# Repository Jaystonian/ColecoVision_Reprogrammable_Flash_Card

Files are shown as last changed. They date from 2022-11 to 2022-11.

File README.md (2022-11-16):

# ColecoVision_Reprogrammable_Flash_Card
An opensource, reprogrammable cartridge for the ColecoVision

MODES OF USE:

A) Single flash chip
- select 32KB or 16KB rom type (J1/JP1)
- select 80-BF for typical 16KB roms, or 80-FF for 32KB roms.
- 2nd flash chip must be absent and its jumpers may be ignored.

B) Dual flash chips (32KB double memory)
- select 16KB rom type (J1/JP1)
- One chip must select 80-BF and contain an array of the lower 16KB of each 32KB rom, the other must select C0-FF and contain the upper 16KB. 
- Your roms will need to be split in half for two 16KB binary files (low and high). Then concatenated into a low file and a high file, for writing.

**NOTES**
All modes require 32KB mode for re-programming flash chips.
Re-programming also requires SW2 switches to all be OPEN and
J2/JP2 must be PROG. Revert jumper back to USE when finished.
The re-programming adapter must have the pullups for block select and a
jumper to select which flash chip to reprogram.

While in 16KB mode, single or dual chip, Address 14 (A14) in SW2 
Memory Select will be included in selecting memory. 32KB mode will
require A14 and this jumper switch will be ignored by J1/JP1 configuration,
allowing the installation of a smaller DIP switch. If you use a single, smaller
Flash chip such as the SST39SF010A (instead of the 'F04) then you do not
need switches for A18 or A17, reducing it to two toggle switches for
four 32KB roms on A15 and A16.

Dual-flash uses dual 16KB for 32KB roms, so the A14 switch is needed to address roms.

8-12KB ROMs must be right-padded to 16KB with 0's.
20-24KB ROMs must be right-padded to 32KB with 0's.

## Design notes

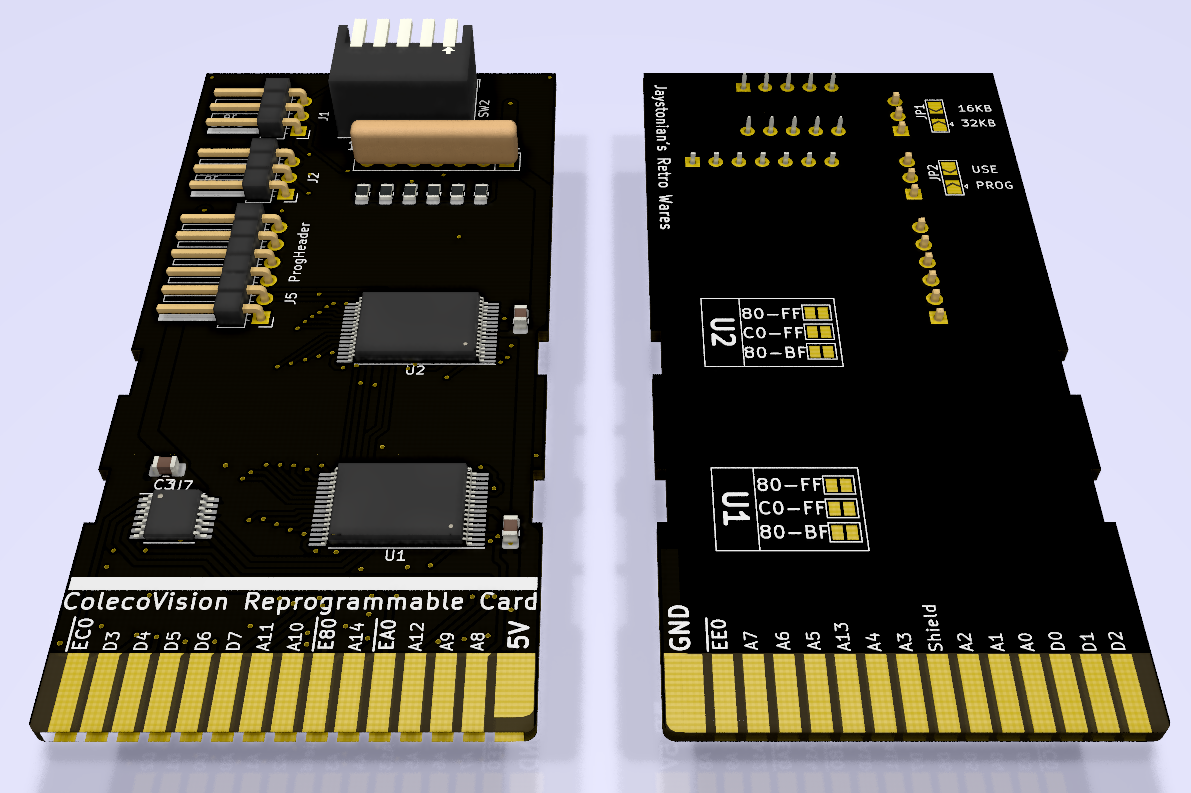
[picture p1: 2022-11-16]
img/Coleco-Card3.png

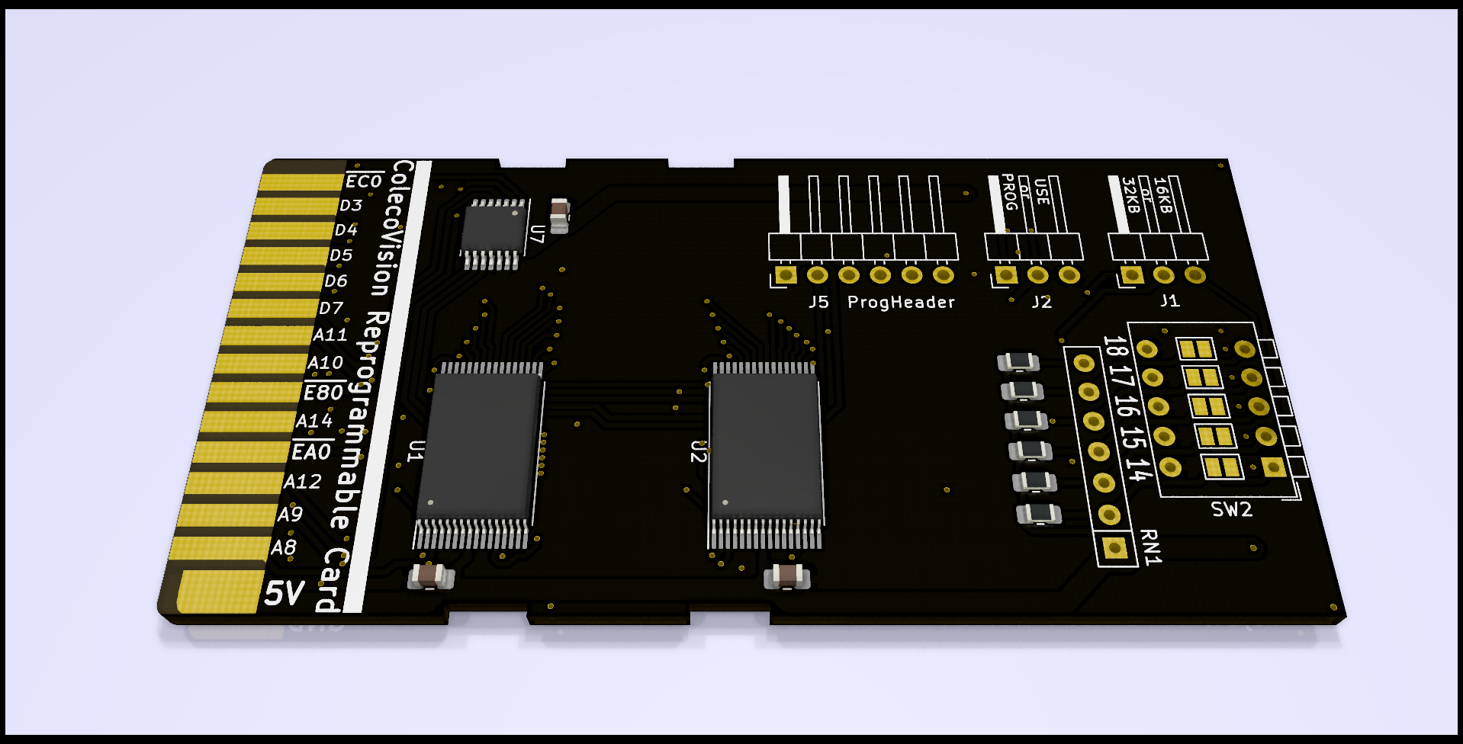
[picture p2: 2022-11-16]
img/Coleco-Card3s.png

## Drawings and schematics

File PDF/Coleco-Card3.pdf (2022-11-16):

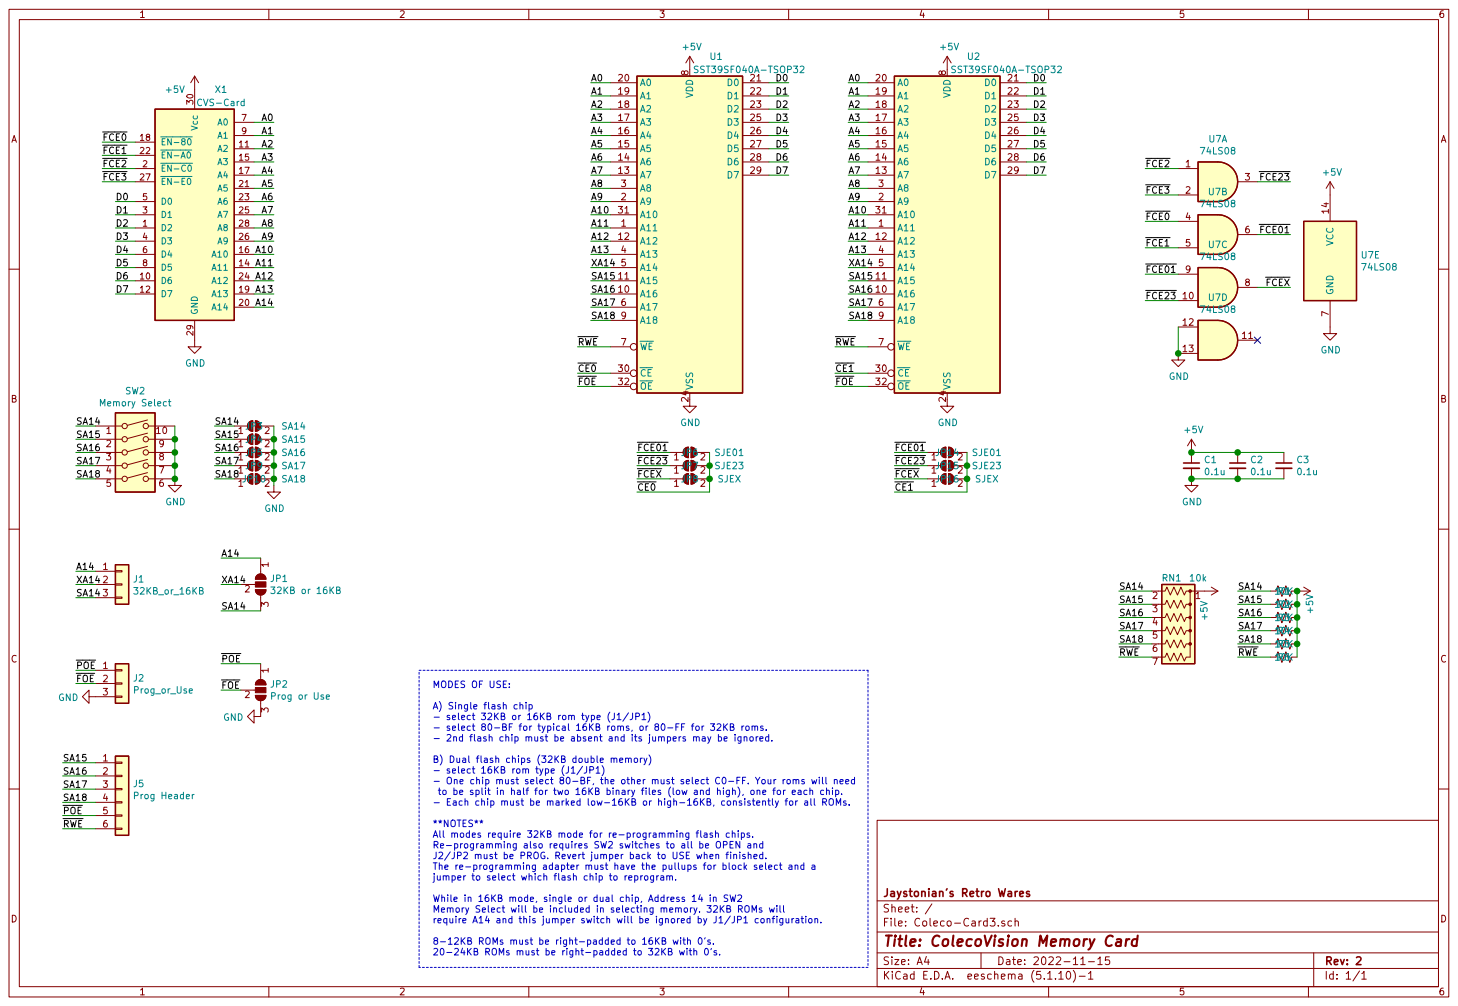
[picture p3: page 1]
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

B) Dual flash chips (32KB double memory)
- select 16KB rom type (J1/JP1)
- One chip must select 80-BF, the other must select C0-FF. Your roms will need
to be split in half for two 16KB binary files (low and high), one for each chip.
- Each chip must be marked low-16KB or high-16KB, consistently for all ROMs. **NOTES** All modes require 32KB mode for re-programming flash chips.

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

File: Coleco-Card3.sch Sheet: / Jaystonian's Retro Wares

While in 16KB mode, single or dual chip, Address 14 in SW2
Memory Select will be included in selecting memory. 32KB ROMs will
require A14 and this jumper switch will be ignored by J1/JP1 configuration.

Id: 1/1 Title: ColecoVision Memory Card

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

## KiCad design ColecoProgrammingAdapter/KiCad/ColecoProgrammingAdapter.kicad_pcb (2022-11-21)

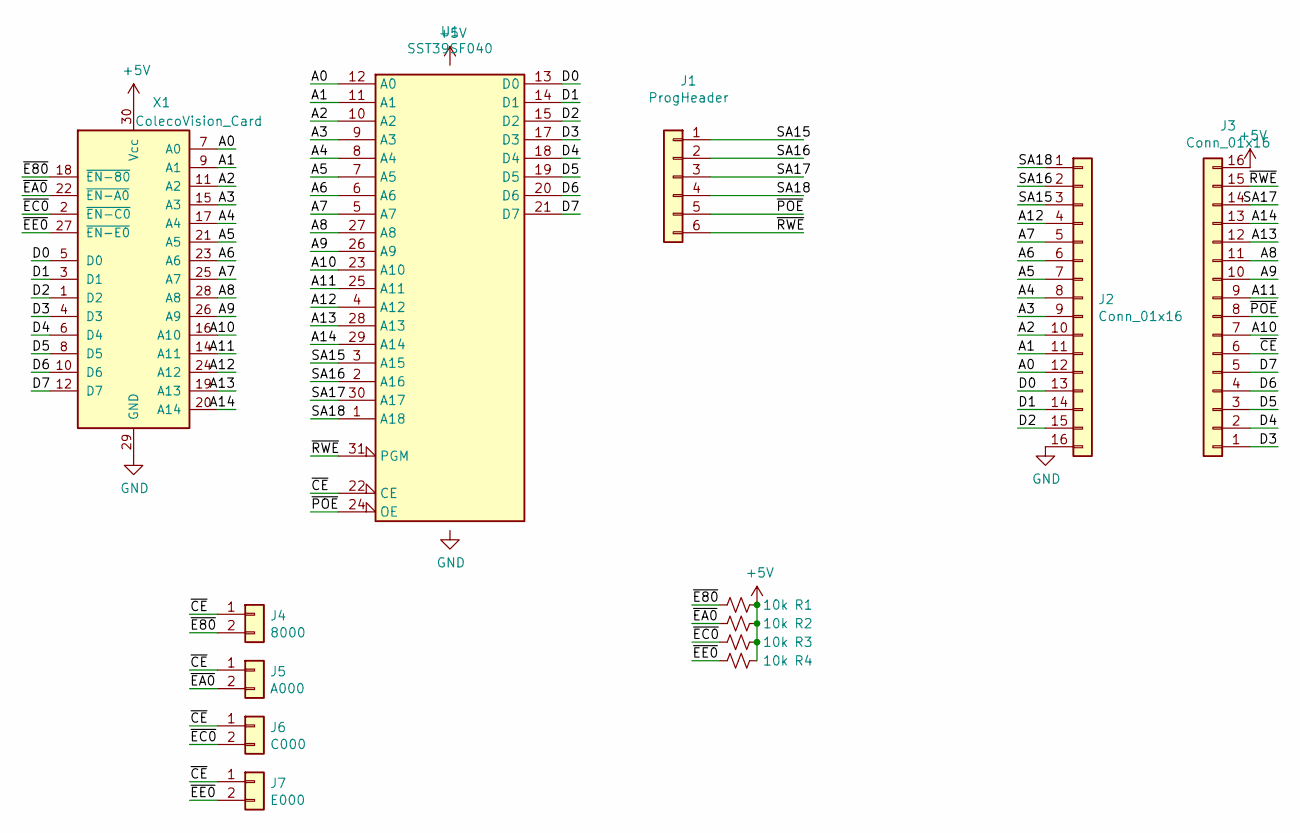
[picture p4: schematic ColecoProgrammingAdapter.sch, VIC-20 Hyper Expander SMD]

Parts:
J1: ProgHeader; PinSocket_1x06_P2.54mm_Vertical
J2, J3: Conn_01x16; PinHeader_1x16_P2.54mm_Vertical
J4: 8000; PinHeader_1x02_P2.54mm_Vertical
J5: A000; PinHeader_1x02_P2.54mm_Vertical
J6: C000; PinHeader_1x02_P2.54mm_Vertical
J7: E000; PinHeader_1x02_P2.54mm_Vertical
R1, R2, R3, R4: 10k; R_0805_2012Metric_Pad1.20x1.40mm_HandSolder
U1: SST39SF040; DIP-32_W15.24mm_Socket
X1: ColecoVision_Card; Coleco_CartridgeConnector

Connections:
+5V: J3.16, R1.1, R2.1, R3.1, R4.1, U1.32 (VCC), X1.30 (Vcc)
/A0: J2.12, U1.12 (A0), X1.7 (A0)
/A1: J2.11, U1.11 (A1), X1.9 (A1)
/A2: J2.10, U1.10 (A2), X1.11 (A2)
/A3: J2.9, U1.9 (A3), X1.15 (A3)
/A4: J2.8, U1.8 (A4), X1.17 (A4)
/A5: J2.7, U1.7 (A5), X1.21 (A5)
/A6: J2.6, U1.6 (A6), X1.23 (A6)
/A7: J2.5, U1.5 (A7), X1.25 (A7)
/A8: J3.11, U1.27 (A8), X1.28 (A8)
/A9: J3.10, U1.26 (A9), X1.26 (A9)
/A10: J3.7, U1.23 (A10), X1.16 (A10)
/A11: J3.9, U1.25 (A11), X1.14 (A11)
/A12: J2.4, U1.4 (A12), X1.24 (A12)
/A13: J3.12, U1.28 (A13), X1.19 (A13)
/A14: J3.13, U1.29 (A14), X1.20 (A14)
/D0: J2.13, U1.13 (D0), X1.5 (D0)
/D1: J2.14, U1.14 (D1), X1.3 (D1)
/D2: J2.15, U1.15 (D2), X1.1 (D2)
/D3: J3.1, U1.17 (D3), X1.4 (D3)
/D4: J3.2, U1.18 (D4), X1.6 (D4)
/D5: J3.3, U1.19 (D5), X1.8 (D5)
/D6: J3.4, U1.20 (D6), X1.10 (D6)
/D7: J3.5, U1.21 (D7), X1.12 (D7)
/SA15: J1.1, J2.3, U1.3 (A15)
/SA16: J1.2, J2.2, U1.2 (A16)
/SA17: J1.3, J3.14, U1.30 (A17)
/SA18: J1.4, J2.1, U1.1 (A18)
/~CE: J3.6, J4.1, J5.1, J6.1, J7.1, U1.22 (CE)
/~E80: J4.2, R1.2, X1.18 (~EN-80)
/~EA0: J5.2, R2.2, X1.22 (~EN-A0)
/~EC0: J6.2, R3.2, X1.2 (~EN-C0)
/~EE0: J7.2, R4.2, X1.27 (~EN-E0)
/~POE: J1.5, J3.8, U1.24 (OE)
/~RWE: J1.6, J3.15, U1.31 (PGM)
GND: J2.16, U1.16 (GND), X1.29 (GND)

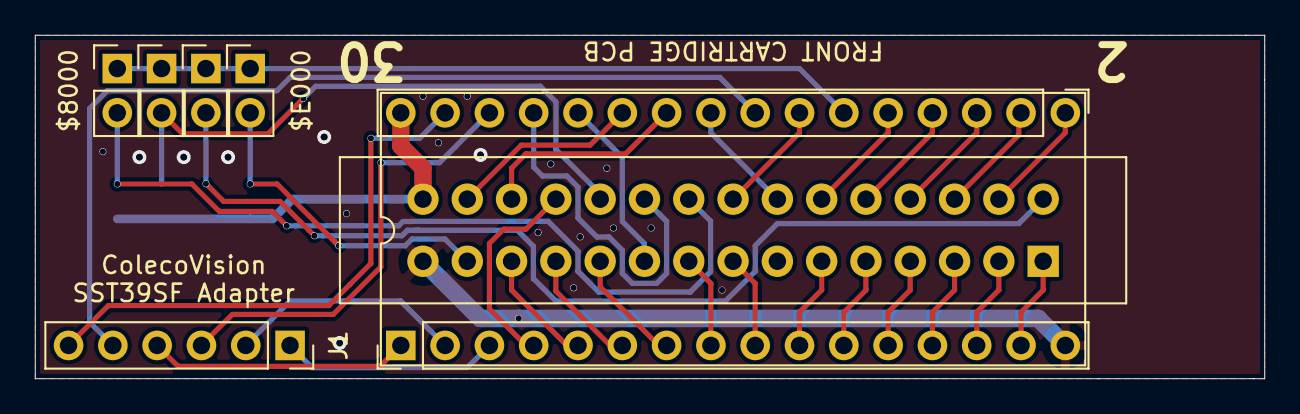
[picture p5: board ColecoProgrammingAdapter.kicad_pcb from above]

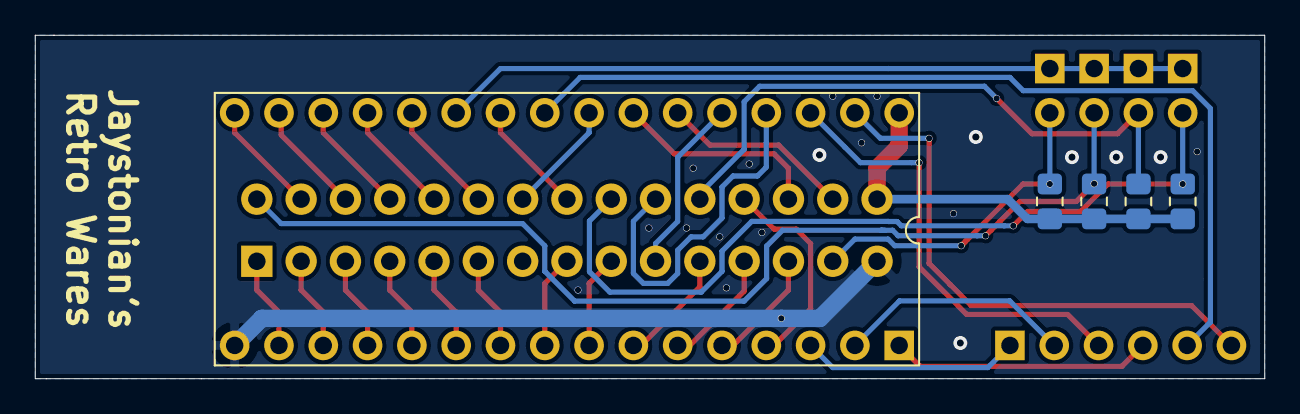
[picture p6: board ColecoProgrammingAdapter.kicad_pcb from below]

Board: 2 copper layers, 70.5 x 19.7 mm, 12 parts (5 on the bottom side), 36 nets.

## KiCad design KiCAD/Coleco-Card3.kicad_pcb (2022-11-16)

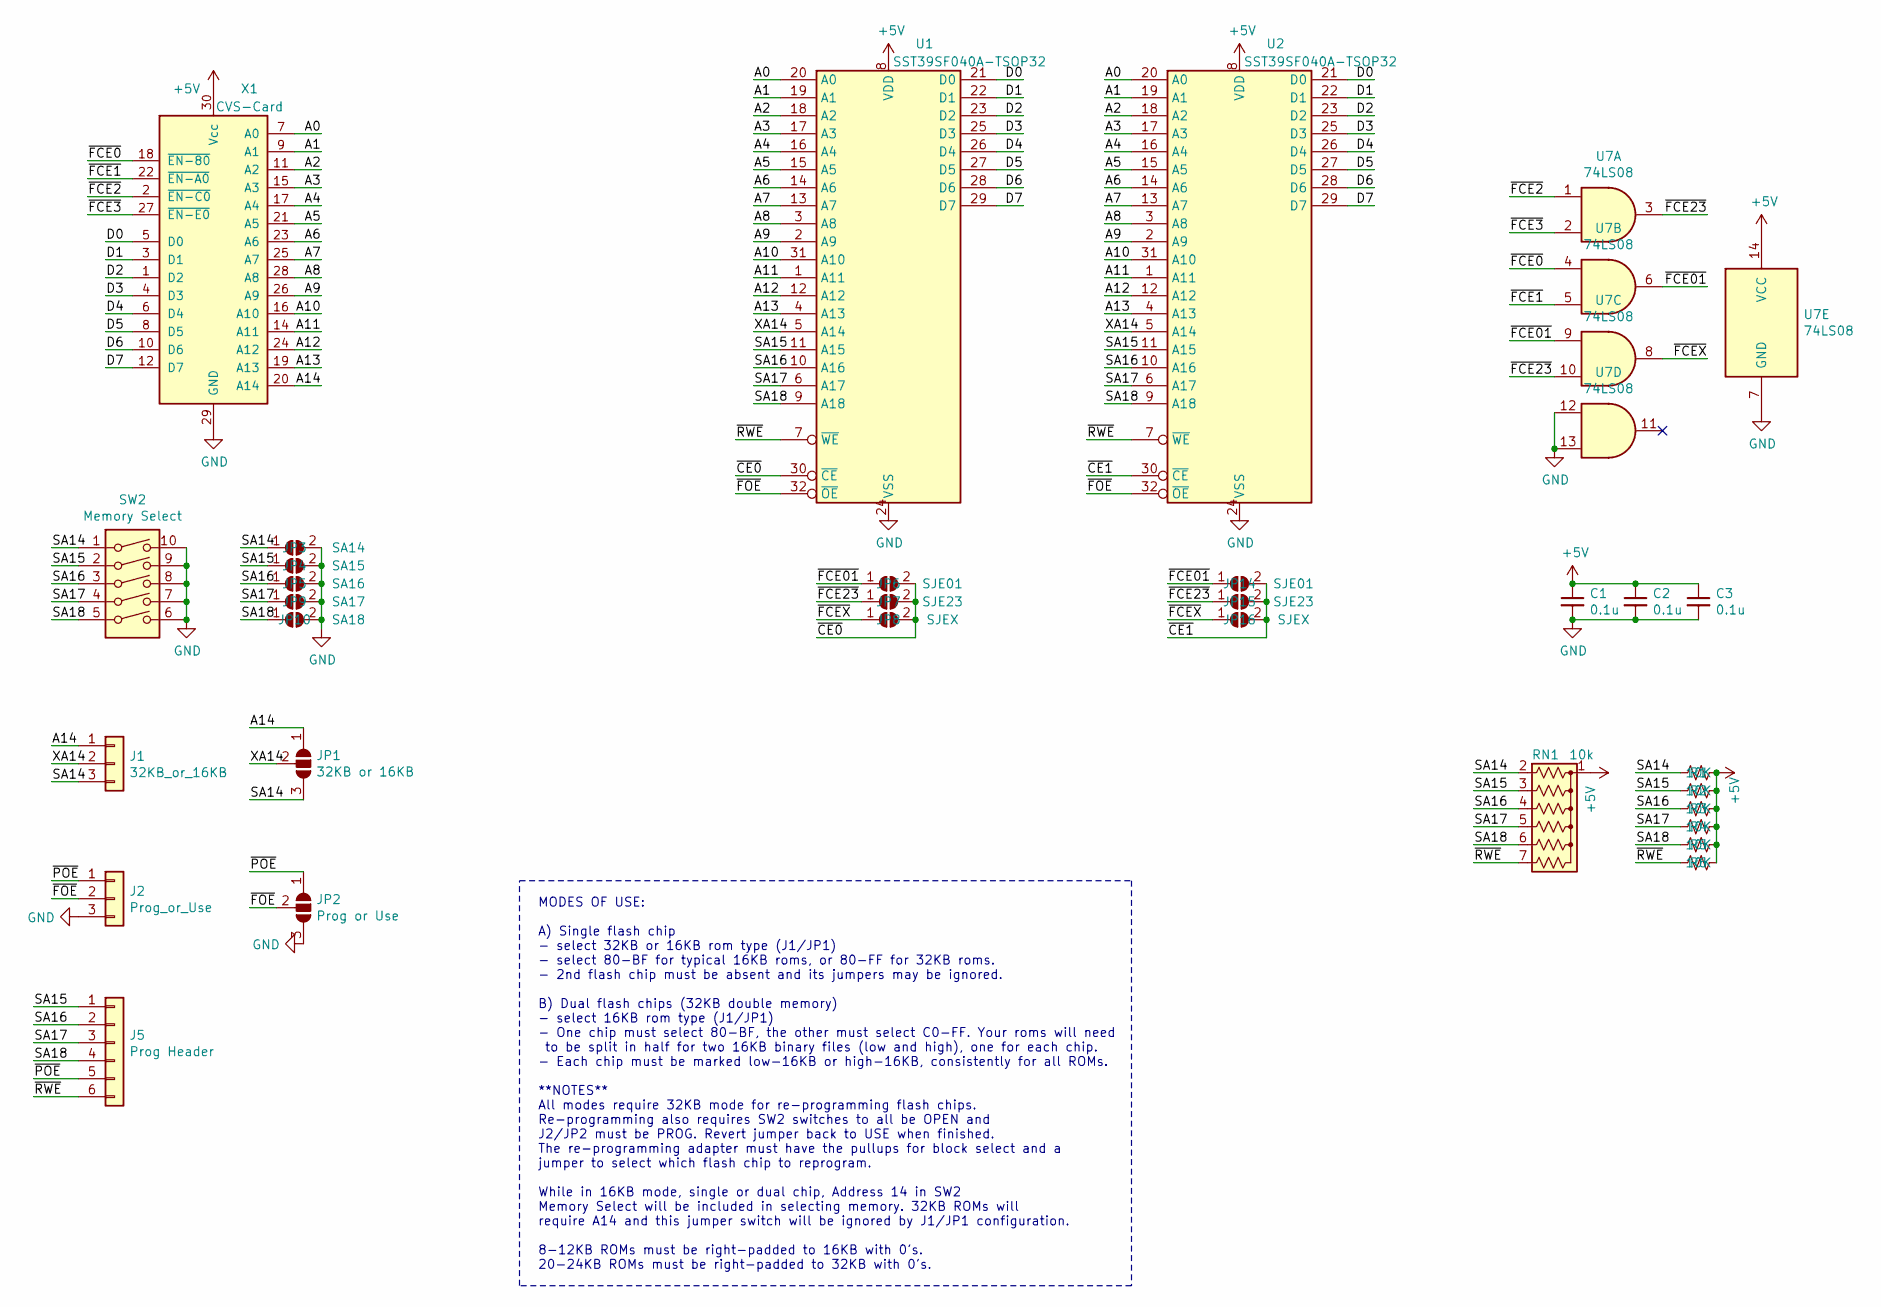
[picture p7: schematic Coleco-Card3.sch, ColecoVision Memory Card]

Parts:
C1, C2, C3: 0.1u; C_0805_2012Metric_Pad1.18x1.45mm_HandSolder
J1: 32KB_or_16KB; PinHeader_1x03_P2.54mm_Horizontal
J2: Prog_or_Use; PinHeader_1x03_P2.54mm_Horizontal
J5: Prog Header; PinHeader_1x06_P2.54mm_Horizontal
JP1: 32KB or 16KB; SolderJumper-3_P2.0mm_Open_TrianglePad1.0x1.5mm
JP2: Prog or Use; SolderJumper-3_P2.0mm_Open_TrianglePad1.0x1.5mm
JP3: SA14; SolderJumper-2_P1.3mm_Open_Pad1.0x1.5mm
JP4: SA15; SolderJumper-2_P1.3mm_Open_Pad1.0x1.5mm
JP5: SA16; SolderJumper-2_P1.3mm_Open_Pad1.0x1.5mm
JP6, JP14: SJE01; SolderJumper-2_P1.3mm_Open_Pad1.0x1.5mm
JP7, JP15: SJE23; SolderJumper-2_P1.3mm_Open_Pad1.0x1.5mm
JP8, JP16: SJEX; SolderJumper-2_P1.3mm_Open_Pad1.0x1.5mm
JP9: SA17; SolderJumper-2_P1.3mm_Open_Pad1.0x1.5mm
JP10: SA18; SolderJumper-2_P1.3mm_Open_Pad1.0x1.5mm
R1, R2, R3, R4, R5, R6: 10K; R_0805_2012Metric_Pad1.20x1.40mm_HandSolder
RN1: 10k; R_Array_SIP7
SW2: Memory Select; SW_DIP_SPSTx05_Piano_CTS_Series194-5MSTN_W7.62mm_P2.54mm
U1, U2: SST39SF040A-TSOP32; TSOP-32_14x8mm_P0.5mm
U7: 74LS08; TSSOP-14_4.4x5mm_P0.65mm
X1: CVS-Card; Coleco_Expansion_Card

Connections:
+5V: C1.1, C2.1, C3.1, R1.1, R2.1, R3.1, R4.1, R5.1, R6.1, RN1.1 (common), U1.8 (VDD), U2.8 (VDD), U7.14 (VCC), X1.30 (Vcc)
/A0: U1.20 (A0), U2.20 (A0), X1.7 (A0)
/A1: U1.19 (A1), U2.19 (A1), X1.9 (A1)
/A2: U1.18 (A2), U2.18 (A2), X1.11 (A2)
/A3: U1.17 (A3), U2.17 (A3), X1.15 (A3)
/A4: U1.16 (A4), U2.16 (A4), X1.17 (A4)
/A5: U1.15 (A5), U2.15 (A5), X1.21 (A5)
/A6: U1.14 (A6), U2.14 (A6), X1.23 (A6)
/A7: U1.13 (A7), U2.13 (A7), X1.25 (A7)
/A8: U1.3 (A8), U2.3 (A8), X1.28 (A8)
/A9: U1.2 (A9), U2.2 (A9), X1.26 (A9)
/A10: U1.31 (A10), U2.31 (A10), X1.16 (A10)
/A11: U1.1 (A11), U2.1 (A11), X1.14 (A11)
/A12: U1.12 (A12), U2.12 (A12), X1.24 (A12)
/A13: U1.4 (A13), U2.4 (A13), X1.19 (A13)
/A14: J1.1, JP1.1 (A), X1.20 (A14)
/D0: U1.21 (D0), U2.21 (D0), X1.5 (D0)
/D1: U1.22 (D1), U2.22 (D1), X1.3 (D1)
/D2: U1.23 (D2), U2.23 (D2), X1.1 (D2)
/D3: U1.25 (D3), U2.25 (D3), X1.4 (D3)
/D4: U1.26 (D4), U2.26 (D4), X1.6 (D4)
/D5: U1.27 (D5), U2.27 (D5), X1.8 (D5)
/D6: U1.28 (D6), U2.28 (D6), X1.10 (D6)
/D7: U1.29 (D7), U2.29 (D7), X1.12 (D7)
/SA14: J1.3, JP1.3 (B), JP3.1 (A), R1.2, RN1.2 (R1), SW2.1
/SA15: J5.1, JP4.1 (A), R2.2, RN1.3 (R2), SW2.2, U1.11 (A15), U2.11 (A15)
/SA16: J5.2, JP5.1 (A), R3.2, RN1.4 (R3), SW2.3, U1.10 (A16), U2.10 (A16)
/SA17: J5.3, JP9.1 (A), R4.2, RN1.5 (R4), SW2.4, U1.6 (A17), U2.6 (A17)
/SA18: J5.4, JP10.1 (A), R5.2, RN1.6 (R5), SW2.5, U1.9 (A18), U2.9 (A18)
/XA14: J1.2, JP1.2 (C), U1.5 (A14), U2.5 (A14)
/~CE0: JP6.2 (B), JP7.2 (B), JP8.2 (B), U1.30 (~CE)
/~CE1: JP14.2 (B), JP15.2 (B), JP16.2 (B), U2.30 (~CE)
/~FCE0: U7.4, X1.18 (~EN-80)
/~FCE1: U7.5, X1.22 (~EN-A0)
/~FCE01: JP6.1 (A), JP14.1 (A), U7.6, U7.9
/~FCE2: U7.1, X1.2 (~EN-C0)
/~FCE3: U7.2, X1.27 (~EN-E0)
/~FCE23: JP7.1 (A), JP15.1 (A), U7.3, U7.10
/~FCEX: JP8.1 (A), JP16.1 (A), U7.8
/~FOE: J2.2, JP2.2 (C), U1.32 (~OE), U2.32 (~OE)
/~POE: J2.1, J5.5, JP2.1 (A)
/~RWE: J5.6, R6.2, RN1.7 (R6), U1.7 (~WE), U2.7 (~WE)
GND: C1.2, C2.2, C3.2, J2.3, JP2.3 (B), JP3.2 (B), JP4.2 (B), JP5.2 (B), JP9.2 (B), JP10.2 (B), SW2.6, SW2.7, SW2.8, SW2.9, SW2.10, U1.24 (VSS), U2.24 (VSS), U7.7 (GND), U7.12, U7.13, X1.29 (GND)

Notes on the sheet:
MODES OF USE: A) Single flash chip - select 32KB or 16KB rom type (J1/JP1) - select 80-BF for typical 16KB roms, or 80-FF for 32KB roms. - 2nd flash chip must be absent and its jumpers may be ignored. B) Dual flash chips (32KB double memory) - select 16KB rom type (J1/JP1) - One chip must select 80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

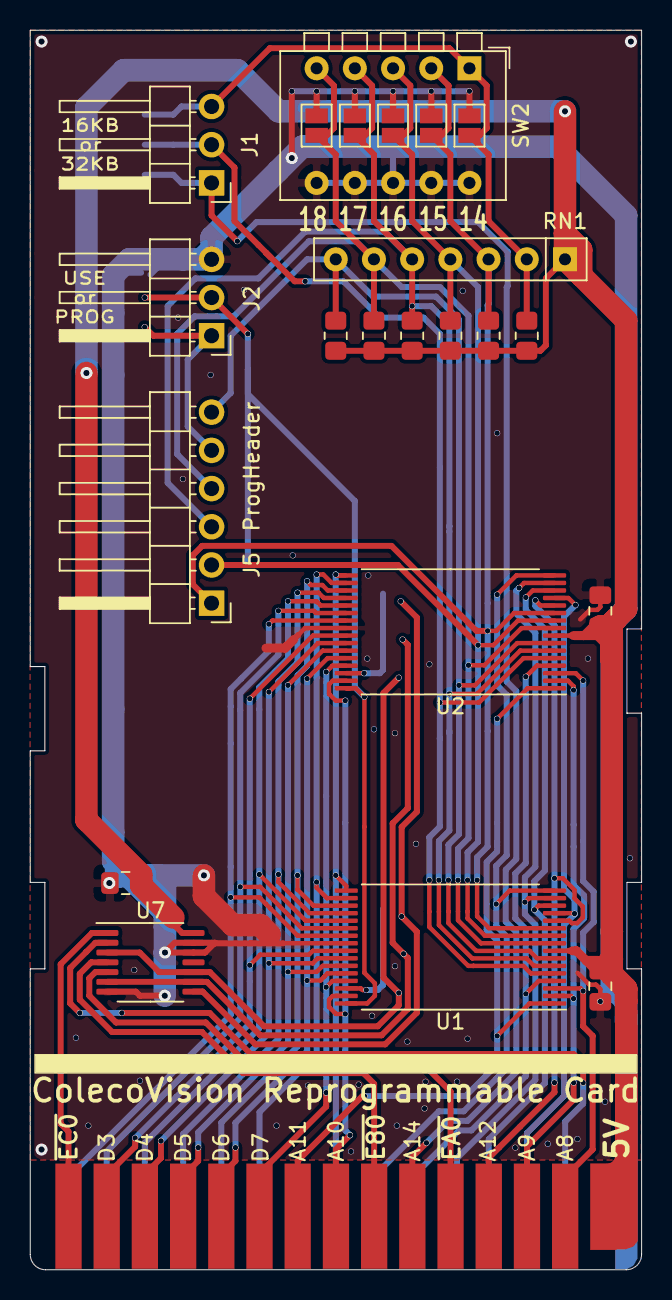
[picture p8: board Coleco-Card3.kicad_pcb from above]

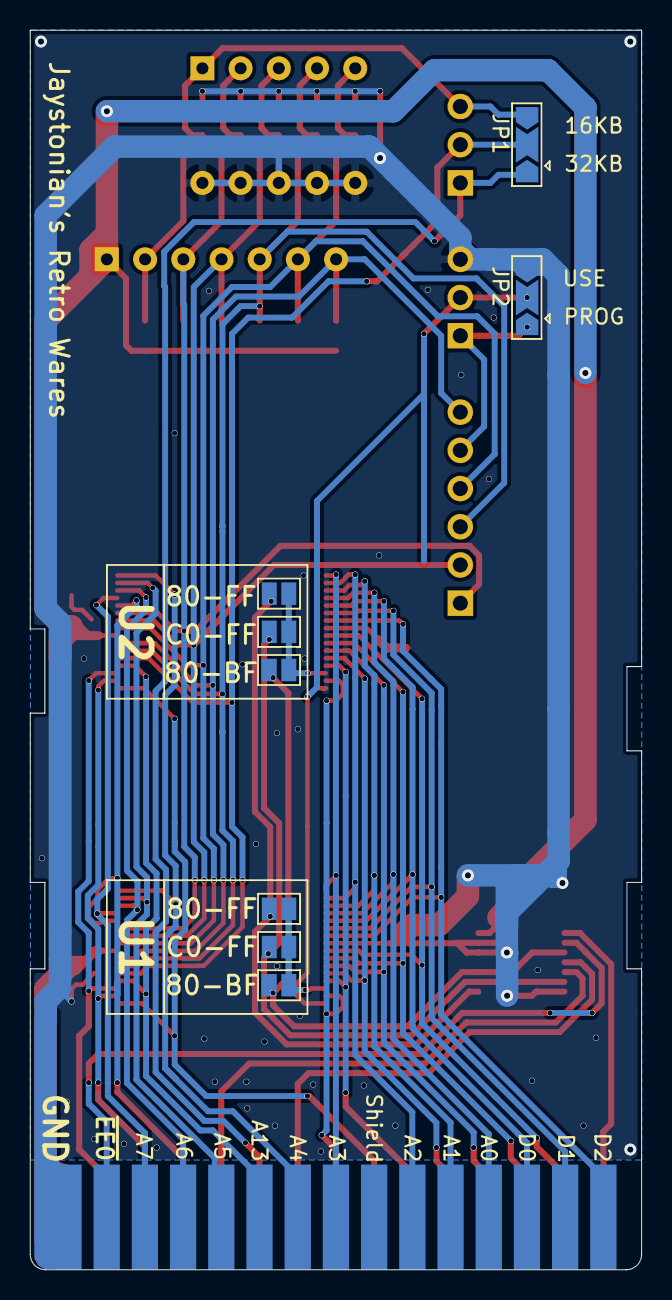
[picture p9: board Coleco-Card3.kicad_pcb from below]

Board: 2 copper layers, 40.6 x 82.4 mm, 31 parts (8 on the bottom side), 43 nets.
